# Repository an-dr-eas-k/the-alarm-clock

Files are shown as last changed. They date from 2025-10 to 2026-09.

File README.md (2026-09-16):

# Intro

# Getting started

1. Write Raspberry Pi OS to sd-card with the use of Raspberry Pi Imager.
   * lite distribution is enough
   * configure login and wifi

1. call the following script 
   * for main:
     ```
     nohup sh -c "curl https://raw.githubusercontent.com/an-dr-eas-k/the-alarm-clock/main/rpi/setup.sh | bash -s" &
     ```

   * for develop:
     ```
     nohup sh -c "curl https://raw.githubusercontent.com/an-dr-eas-k/the-alarm-clock/refs/heads/develop/rpi/setup.sh | bash -s" &
     ```

    * after: 
      ```
      reboot
      ```

    * repeat:
      ```
      nohup sh -c "curl https://raw.githubusercontent.com/an-dr-eas-k/the-alarm-clock/refs/heads/develop/rpi/setup.sh | bash -s -- fast" &
      ```

1. follow the log output with
   * for the application itself
     ```
     journalctl SYSLOG_IDENTIFIER=the-alarm-clock.service -f
     ```
   * for spotify events
     ```
     journalctl SYSLOG_IDENTIFIER=the-alarm-clock.spotify-event.service -f
     ```

# Dependencies
7 Segment Font is included from https://github.com/keshikan/DSEG/releases \
weather symbols are included from https://github.com/erikflowers/weather-icons

# Google Login & Calendar Integration

The web UI can require a Google login to edit settings, and it can show
calendar events (and play a reminder sound shortly before an accepted
event starts) for the Google accounts that logged in.

Since the device has no stable, publicly reachable hostname, login uses
Google's **OAuth 2.0 Device Authorization flow** (the same mechanism used by
smart TVs/streaming devices). No redirect URI is needed — Google's servers
never contact the device directly; the user just opens a short link on
their phone or computer and enters a short code shown by the alarm clock.

Setup:
1. In the [Google Cloud Console](https://console.cloud.google.com/), create
   an OAuth 2.0 Client ID of type **"TV and Limited Input devices"**.
2. Enable the **Google Calendar API** for the project.
3. Save the resulting client id/secret as
   `src/resources/google_oauth_secret.json`:
   ```json
   {
     "client_id": "....apps.googleusercontent.com",
     "client_secret": "...."
   }
   ```
   This file is git-ignored and never leaves the device.
4. Add the Google account email addresses that are allowed to log in to
   `allowed_google_emails` in `config.json` (or via the web UI's Config
   section once you have logged in once, e.g. by temporarily adding your own
   email directly to `config.json`).
5. Log in from the web UI ("Login with Google"): it shows a code and a link
   to `google.com/device` — open it on any device and enter the code.
6. Once logged in, the linked account's calendar is polled periodically;
   events starting within the next hour are shown on the display, and a
   configurable reminder sound plays a few seconds before any *accepted*
   event starts.

All related settings (reminder sound, lead time, poll interval, display
window) are editable in the web UI's Config section once logged in.

# Box

## Simple

# Connection Guide
## RPi GPIO

| |||||||||
|---|---|---|----|---|----|---|---|---|
| blue |  i2c (vcc) | 3V3 |  1 | |  2 | 5V  | | |
| green |  i2c (sda) | GPIO02 |  3 | |  4 | 5V  | | |
| yellow  |  i2c (scl) | GPIO03 |  5 | |  6 | GND  | | |
| purple  |  i2c (int) | GPIO04 |  7 | |  8 | GPIO14  | | |
| | | GND |  9 | | 10 | GPIO15  | | |
| | | GPIO17 | 11 | | 12 | GPIO18  | i2s (digiamp+)  | |
| | | GPIO27 | 13 | | 14 | GND  | | |
| | | GPIO22 | 15 | | 16 | GPIO23  | | |
| red | spi (vbat, 2)  | 3V3 | 17 | | 18 | GPIO24  | spi ( dc, 14) | gray  |
| white | spi ( sdi, 5)  | GPIO10 | 19 | | 20 | GND  | spi (  vss,  1) |  black  |
| | | GPIO09 | 21 | | 22 | GPIO25  | spi (reset, 15) | pink  |
| brown | spi (sclk, 4)  | GPIO11 | 23 | | 24 | GPIO08  | spi ( cs, 16) | blue  |
| | | GND | 25 | | 26 | GPIO07  | | |
| | | GPIO00 | 27 | | 28 | GPIO01  | invoke_button | |
| | rot_press | GPIO05 | 29 | | 30 | GND  | | |
| | rot_a | GPIO06 | 31 | | 32 | GPIO12  | mode_button | |
| | rot_b | GPIO13 | 33 | | 34 | GND  | | |
| | i2s (digiamp+) | GPIO19 | 35 | | 36 | GPIO16  | | |
| | | GPIO26 | 37 | | 38 | GPIO20  |  i2s (digiamp+) | |
| black | ground term | GND | 39 | | 40 | GPIO21  |  i2s (digiamp+) | |

## MCP 23017

| |||||||||
|---|---|----|---|---|---|---|---|---|
| | A3 | | VCC |  blue  | BH1759 | GND | | |
| | A2 | | ITB *1 | | | ITA *1  |  purple  | rpi gpio4 |
| | A1 | | B0 |  brown | rotary button | A0 |  white | mode button |
| | Reset | | B1 |  black | rotary 1 | A1 |  grey | invoke button |
| | NC | | B2 |  red | rotary 2 | A2 | | |
| | NC | | B3 | | | A3 | | |
| green | SDA | | B4 | | | A4 | | |
| orange  | SCL | | B5 | | | A5 | | |
| purple  | GND | | B6 | | | A6 | | |
| orange  | VCC | | B7 | | | A7 | | |

# State Diagram

|State|1|2|3|4| Comment|
|---|-----|-----|--|--| --|
|Default|Default,<br>Volume Timer|Default,<br> Volume Timer|AlarmView|Media On, Playing|
|Volume Timer | 
|AlarmView | AlarmView,<br>Previous Alarm | AlarmView,<br>Next Alarm | Default|AlarmEdit |There is a `new Alarm` Alarm|
|AlarmEdit | AlarmEdit,<br>Previous Property|AlarmEdit,<br>Next Property|Default|PropertyEdit|There is a `save` Property|
|PropertyEdit | PropertyEdit,<br>Value Down | PropertyEdit,<br>Value Up| Default | AlarmEdit|

# Devices
## Rotary Encoder
## Light Sensor BH1750
## Port Expander 16-Bit-I/O MCP23017 
## Sound card DigiAMP+

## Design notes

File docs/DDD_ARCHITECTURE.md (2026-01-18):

# Domain-Driven Design Architecture

## Layer Overview

This project follows **Domain-Driven Design (DDD)** principles with clear separation of concerns across four layers:

```
┌─────────────────────────────────────────────────────────┐
│                    INTERFACE LAYER                       │
│  (User interaction, Hardware I/O, API endpoints)        │
│                                                          │
│  • display/display_content.py  (ViewModel - MVVM)       │
│  • display/presenter.py         (View logic)             │
│  • display/format.py            (Display formatting)     │
│  • hardware_input_handler.py   (Hardware → Domain)      │
│  • web/template.html            (Web UI)                 │
└─────────────────────────────────────────────────────────┘
                          ↓ depends on
┌─────────────────────────────────────────────────────────┐
│                   APPLICATION LAYER                      │
│  (Use cases, orchestration, workflows)                  │
│                                                          │
│  • controls.py                  (Main orchestrator)      │
│  • api.py                       (REST API handlers)      │
│  • di_container.py              (Dependency injection)   │
└─────────────────────────────────────────────────────────┘
                          ↓ depends on
┌─────────────────────────────────────────────────────────┐
│                     DOMAIN LAYER                         │
│  (Pure business logic, no technical dependencies)       │
│                                                          │
│  Aggregates:                                             │
│  • AlarmClockContext            (Aggregate Root)         │
│  • EnvironmentContext           (Environment state)      │
│  • Config                       (Configuration)          │
│                                                          │
│  Entities:                                               │
│  • AlarmDefinition              (Alarm configuration)    │
│  • AlarmClockModeCoordinator    (UI mode management)     │
│                                                          │
│  Value Objects:                                          │
│  • RoomBrightness               (Display brightness)     │
│  • AudioStream, AudioEffect     (Audio configuration)    │
│  • VisualEffect                 (Alarm visual effects)   │
│                                                          │
│  Domain Events:                                          │
│  • AudioStreamChangedEvent                               │
│  • VolumeChangedEvent                                    │
│  • AlarmEvent                                            │
└─────────────────────────────────────────────────────────┘
                          ↓ depends on
┌─────────────────────────────────────────────────────────┐
│                 INFRASTRUCTURE LAYER                     │
│  (External systems, persistence, hardware)              │
│                                                          │
│  • audio.py                     (VLC playback)           │
│  • persistence.py               (JSON storage)           │
│  • brightness_sensor.py         (BH1750 sensor)          │
│  • event_bus.py                 (Event infrastructure)   │
│  • mcp23017/                    (Hardware buttons)       │
└─────────────────────────────────────────────────────────┘
```

## Key DDD Patterns Implemented

### 1. **Aggregates**

**AlarmClockContext** (Aggregate Root)
- Central entry point for domain operations
- Coordinates Config, EnvironmentContext, and ModeCoordinator
- Enforces invariants and business rules
- Location: `core/domain/model.py`

**EnvironmentContext** (Aggregate)
- Encapsulates environmental state (weather, network, location)
- Owned by AlarmClockContext
- Location: `core/domain/model.py`

### 2. **Value Objects**

**RoomBrightness**
- Immutable value representing ambient brightness
- Contains behavior: `is_highly_dimmed()`, `get_grayscale_value()`
- Used throughout the system for consistent brightness handling

**NextAlarmInfo**
- Immutable value representing next alarm timing
- Shields domain from infrastructure (APScheduler Job)
- Location: `core/interface/display/display_content.py`

### 3. **Entities**

**AlarmDefinition**
- Has identity (id field)
- Mutable lifecycle (can be edited, activated/deactivated)
- Rich domain behavior: `to_cron_trigger()`, `is_recurring()`

**AlarmClockModeCoordinator**
- Domain entity managing UI mode transitions
- Isolated from hardware through HardwareInputHandler

### 4. **Domain Events**

Events represent **business facts** that happened:
- `AlarmEvent` - An alarm was triggered
- `AudioStreamChangedEvent` - Audio source changed
- `VolumeChangedEvent` - Volume was adjusted
- `WifiStatusChangedEvent` - Network connectivity changed

Located in: `core/domain/events.py`

### 5. **Repositories** (Future Enhancement)

Currently using direct persistence, but planned:
```python
# core/repositories.py
class AlarmDefinitionRepository(ABC):
    @abstractmethod
    def get_by_id(self, id: int) -> AlarmDefinition: ...
    
    @abstractmethod
    def save(self, alarm: AlarmDefinition): ...
```

### 6. **Application Services**

**Controls** (Application Service)
- Orchestrates domain operations
- Coordinates between aggregates
- Manages scheduler and external systems
- Does NOT contain business logic (delegates to domain)

**AlarmEditingService** (Application Service)
- Manages alarm editing workflow
- Uses AlarmEditingSession aggregate
- Coordinates UI state with domain changes

### 7. **Anti-Corruption Layer**

**HardwareInputHandler** (Interface Layer)
- Translates hardware events (HwButtonEvent) to domain commands
- Prevents infrastructure leakage into domain
- Maps rotary encoder events to volume adjustments

**DisplayContent** (Interface Layer)
- ViewModel pattern (MVVM)
- Aggregates domain data for presentation
- Shields View from domain complexity

## Layering Rules (Dependency Inversion)

### ✅ Allowed Dependencies

```
Interface → Application → Domain → (nothing)
Infrastructure → Domain (via interfaces)
```

### ❌ Forbidden Dependencies

```
Domain → Infrastructure  ❌
Domain → Interface       ❌
Domain → Application     ❌
```

## Example: Adding a New Feature (DDD Way)

**Scenario:** Add "snooze alarm" feature

### 1. **Domain Layer** (Business Logic)
```python
# core/domain/model.py
class AlarmDefinition:
    def snooze(self, minutes: int = 10) -> datetime:
        """
        Business rule: Snooze moves alarm forward by configured minutes.
        Returns the new alarm time.
        """
        if not self.is_active:
            raise DomainException("Cannot snooze inactive alarm")
        
        snooze_time = GeoLocation().now() + timedelta(minutes=minutes)
        self.set_future_date(snooze_time.hour, snooze_time.minute)
        return snooze_time
```

### 2. **Application Layer** (Orchestration)
```python
# core/application/controls.py
def snooze_current_alarm(self):
    """
    Application service: Orchestrates snooze operation.
    """
    alarm_def = self._get_current_alarm()
    new_time = alarm_def.snooze(self.config.snooze_duration_mins)
    
    # Reschedule in infrastructure
    self.scheduler.add_job(...)
    
    # Emit domain event
    self.event_bus.emit(AlarmSnoozedEvent(new_time))
```

### 3. **Interface Layer** (User Interaction)
```python
# core/interface/hardware_input_handler.py
def _handle_snooze_button(self, event: HwButtonEvent):
    """
    Translate hardware button to domain command.
    """
    self.mode_coordinator.snooze_alarm()
```

### 4. **Infrastructure Layer** (External Systems)
```python
# core/infrastructure/audio.py
def stop_alarm_playback(self):
    """Stop VLC playback (infrastructure detail)."""
    self.player.stop()
```

## Benefits of This Architecture

### 1. **Testability**
- Domain logic testable without hardware
- Mock interfaces for infrastructure
- Unit test business rules in isolation

### 2. **Flexibility**
- Swap VLC for another audio player
- Replace JSON persistence with database
- Change display technology without touching domain

### 3. **Maintainability**
- Business logic concentrated in domain layer
- Clear responsibility boundaries
- Changes localized to appropriate layers

### 4. **Ubiquitous Language**
- Code speaks the business domain
- `AlarmDefinition.snooze()` not `schedule_timer()`
- `EnvironmentContext.is_daytime` not `check_sun_api()`

## Migration Path

### Current State (✅ Completed)
- [x] Domain layer separated from infrastructure
- [x] DisplayContent moved to interface layer
- [x] HardwareInputHandler as anti-corruption layer
- [x] Aggregates with clear boundaries

### Next Steps (Recommended)
- [ ] Extract PlaybackContent to interface layer
- [ ] Implement Repository pattern for persistence
- [ ] Move audio player creation to factory in infrastructure
- [ ] Add domain event sourcing for audit trail
- [ ] Create bounded contexts for complex domains

## File Organization

```
src/core/
├── domain/                    # PURE BUSINESS LOGIC
│   ├── model.py              # Aggregates, Entities, Value Objects
│   ├── mode_coordinator.py   # Mode management entity
│   ├── edit_mode.py          # Editing workflow
│   └── events.py             # Domain events
│
├── application/               # ORCHESTRATION
│   ├── controls.py           # Main application service
│   ├── api.py                # REST API handlers
│   └── di_container.py       # Dependency injection
│
├── interface/                 # USER/HARDWARE INTERACTION
│   ├── display/
│   │   ├── display_content.py    # ViewModel (THIS IS KEY!)
│   │   ├── presenter.py          # View logic
│   │   └── format.py             # Display formatting
│   ├── hardware_input_handler.py # Hardware → Domain
│   └── web/                      # Web interface
│
└── infrastructure/            # EXTERNAL SYSTEMS
    ├── audio.py              # VLC integration
    ├── persistence.py        # JSON storage
    ├── event_bus.py          # Event infrastructure
    └── mcp23017/             # Hardware drivers
```

## Key Takeaway

**The domain layer knows NOTHING about:**
- Display technology (OLED, TFT, etc.)
- Audio players (VLC, mpg123, etc.)
- Persistence (JSON, SQLite, etc.)
- Hardware (buttons, sensors, etc.)
- Web frameworks (Tornado, Flask, etc.)

**The domain layer knows ONLY:**
- Alarms can be snoozed
- Alarms have recurrence patterns
- Volume has min/max limits
- Weather affects display brightness

This is the essence of Domain-Driven Design!

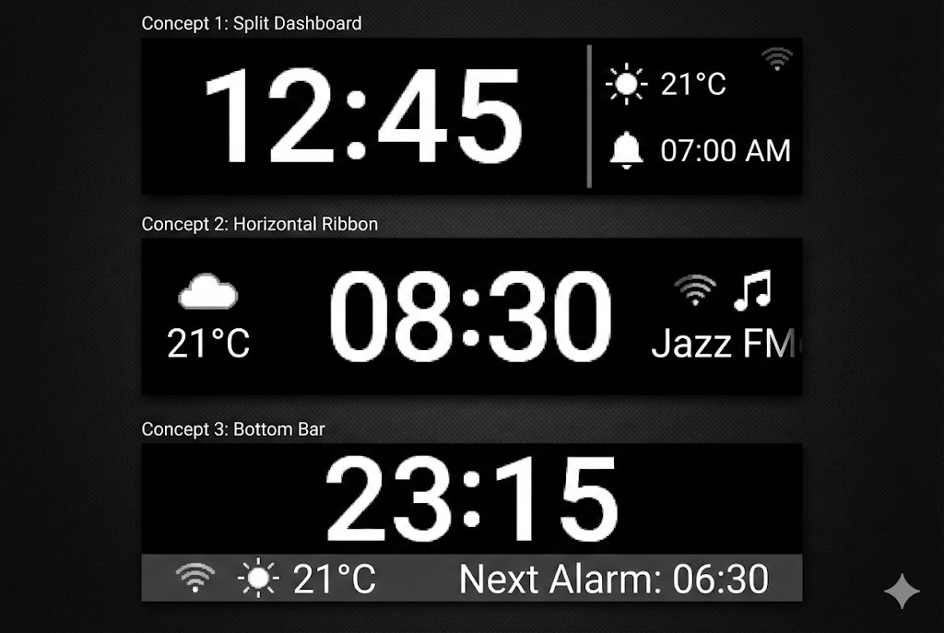
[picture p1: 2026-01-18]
docs/display_concepts.jpg

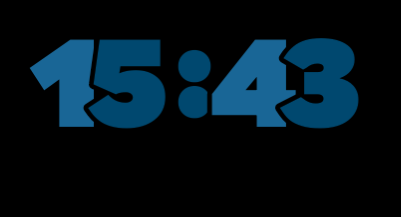
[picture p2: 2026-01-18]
docs/share_7980132162714593532.png

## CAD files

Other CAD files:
case/simple.dxf

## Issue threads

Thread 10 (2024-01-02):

action buttons in alarm.html

an-dr-eas-k, 2024-01-02:
update, reboot, and shutdown

Closed 2024-01-04.

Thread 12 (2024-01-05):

Dismiss alarm, repeat off button, why?

an-dr-eas-k, 2024-01-05:

an-dr-eas-k, 2024-01-30:
no idea, loose hardware connection

Closed 2024-01-30.

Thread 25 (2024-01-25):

display issues

an-dr-eas-k, 2024-01-25:
1. first digit in hour is malformed (done)
2. positive temperature, use ! instead of ' ' (done)
3. after bright display, flash with black
4. Transparent subtleness (fonts are more anti-aliased than needed. need to look into the way, the transparent layers are merged)

an-dr-eas-k, 2024-01-26:
1 and 2 are solved now

Closed 2024-03-19.

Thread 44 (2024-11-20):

Volume timer problem with offline alarm

an-dr-eas-k, 2024-11-20:
Volume Meter is showing when offline alarm chimes and is not dismissed automatically

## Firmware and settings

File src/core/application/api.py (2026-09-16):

import base64
import io
import logging
import os
import json
import subprocess
import traceback
import tornado
from concurrent.futures import ThreadPoolExecutor
import tornado.ioloop
import tornado.web
from PIL.Image import Image
from core.application.alarm_audio_service import AlarmAudioService
from core.application.calendar_service import CalendarService
from core.domain.events import (
    PlaybackChangedEvent,
    ConfigChangedEvent,
    ShutdownSystemRequest,
    SpotifyApiEvent,
    TerminateAppRequest,
    VolumeChangeRequest,
    WifiStatusChangedEvent,
)
from core.infrastructure.event_bus import EventBus
from core.interface.display.display import Display
from core.interface.display.format import ColorType
from core.interface.web.auth import (
    CurrentUserMixin,
    GoogleLoginPollHandler,
    GoogleLoginStartHandler,
    LogoutHandler,
)
from resources.resources import webroot_file, ssl_dir, icons_dir, fonts_dir

from core.domain.model import (
    AlarmDefinition,
    AudioEffect,
    AudioStream,
    Config,
    DisplayContentProvider,
    Mode,
    StreamAudioEffect,
    VisualEffect,
    Weekday,
)

logger = logging.getLogger("tac.core.application.api")


def try_update(object, property_name: str, value: str) -> bool:
    if hasattr(object, property_name):
        attr_value = getattr(object, property_name)
        attr_type = type(attr_value)
        if attr_type == bool:
            value = value.lower() in ["on", "yes", "true", "t", "1"]
        elif attr_type == list:
            value = json.loads(value) if value else []
        else:
            value = attr_type(value) if len(value) > 0 else None
        if value != attr_value:
            setattr(object, property_name, value)
        return True
    return False


def parse_path_arguments(path) -> tuple[str, int, str]:
    path_args = path[0].split("/")
    return (
        path_args[0],
        int(path_args[1]) if len(path_args) > 1 else None,
        path_args[2] if len(path_args) > 2 else None,
    )


class LibreSpotifyEventHandler(tornado.web.RequestHandler):

    def initialize(self, event_bus: EventBus, executor: ThreadPoolExecutor) -> None:
        self.event_bus = event_bus
        self.executor = executor

    def post(self):
        self.executor.submit(self.handle_spotify_event)
        self.finish()

    def handle_spotify_event(self):
        try:
            body = (
                "{}"
                if self.request.body is None or len(self.request.body) == 0
                else self.request.body
            )
            spotify_event_payload: dict[str, str] = tornado.escape.json_decode(body)

            spotify_event_dict = {
                key: value for key, value in spotify_event_payload.items()
            }

            spotify_event = SpotifyApiEvent(spotify_event_dict)
            logger.info("received librespotify event %s", spotify_event)
            self.event_bus.emit(spotify_event)
        except Exception:
            logger.warning("%s", traceback.format_exc())


class DisplayHandler(tornado.web.RequestHandler):

    def initialize(self, display: DisplayContentProvider) -> None:
        self.display = display

    def get(self):
        buffered = io.BytesIO()
        img = self.display.current_display_image
        assert isinstance(img, Image)
        img.save(buffered, format="png")
        img.seek(0)
        img_str = base64.b64encode(buffered.getvalue())
        my_html = '<img src="data:image/png;base64, {}">'.format(
            img_str.decode("utf-8")
        )
        self.write(my_html)


class ConfigHandler(CurrentUserMixin, tornado.web.RequestHandler):

    def initialize(self, config: Config, api: "Api") -> None:
        self.config = config
        self.api = api

    def get(self, *args, **kwargs):
        try:
            self.render(
                os.path.basename(webroot_file),
                config=self.config,
                api=self.api,
                calendar_events=self.api.calendar_service.get_upcoming_events(),
                current_user_picture=self.get_current_user_picture(),
            )
        except:
            logger.warning("%s", traceback.format_exc())


class ActionApiHandler(CurrentUserMixin, tornado.web.RequestHandler):

    def initialize(self, config: Config, event_bus: EventBus) -> None:
        self.config = config
        self.event_bus = event_bus

    @tornado.web.authenticated
    def post(self, *args):
        try:
            type, id, _1 = parse_path_arguments(args)
            logger.info("API action requested: %s %s", type, id)

            if type == "play":
                self.event_bus.emit(
                    PlaybackChangedEvent(
                        playback_mode=Mode.Music,
                        audio_stream=self.config.get_audio_stream_by_id(id),
                    )
                )
            elif type == "stop":
                self.event_bus.emit(PlaybackChangedEvent(Mode.Idle))
            elif type == "volume":
                if id == 1:
                    self.event_bus.emit(VolumeChangeRequest(relative=+1))
                else:
                    self.event_bus.emit(VolumeChangeRequest(relative=-1))
            elif type == "update":
                self.event_bus.emit(TerminateAppRequest())

                tornado.ioloop.IOLoop.current().stop()

            elif type == "reboot":
                self.event_bus.emit(ShutdownSystemRequest(reboot=True))
            elif type == "shutdown":
                self.event_bus.emit(ShutdownSystemRequest())
            else:
                logger.warning("Unknown action: %s", type)

        except:
            logger.warning("%s", traceback.format_exc())


class SystemApiHandler(CurrentUserMixin, tornado.web.RequestHandler):

    def initialize(self, event_bus: EventBus) -> None:
        self.event_bus = event_bus

    @tornado.web.authenticated
    def post(self, *args):
        try:
            type, _, _ = parse_path_arguments(args)
            logger.info("System API action requested: %s", type)

            if type == "wifi":
                status = self.get_argument("status", None)
                if status == "connected":
                    self.event_bus.emit(WifiStatusChangedEvent(is_online=True))
                elif status == "disconnected":
                    self.event_bus.emit(WifiStatusChangedEvent(is_online=False))
                else:
                    logger.warning("Unknown wifi status: %s", status)
            else:
                logger.warning("Unknown system action: %s", type)

        except:
            logger.warning("%s", traceback.format_exc())


class ConfigApiHandler(CurrentUserMixin, tornado.web.RequestHandler):

    def initialize(self, config: Config, event_bus: EventBus) -> None:
        self.config = config
        self.event_bus = event_bus

    def get(self):
        try:
            self.set_header("Content-Type", "application/json")
            self.write(self.config.serialize())
        except:
            logger.warning("%s", traceback.format_exc())

    @tornado.web.authenticated
    def delete(self, *args):
        try:
            self.parse_delete_payload(args)
            self.event_bus.emit(ConfigChangedEvent(self.config))
        except:
            logger.warning("%s", traceback.format_exc())

    def parse_delete_payload(self, args):
        type, id, _ = parse_path_arguments(args)
        if type == "alarm":
            self.config.remove_alarm_definition(id)
        elif type == "stream":
            self.config.remove_audio_stream(id)

    @tornado.web.authenticated
    def post(self, *args):
        try:
            self.parse_post_payload(args)
            self.event_bus.emit(ConfigChangedEvent(self.config))
        except:
            logger.warning("%s", traceback.format_exc())

    def parse_post_payload(self, args):
        type, id, property = parse_path_arguments(args)
        simpleValue = tornado.escape.to_unicode(self.request.body)
        if try_update(self.config, type, simpleValue):
            return
        alarmDef = self.config.get_alarm_definition_by_id(id)
        if (
            True
            and alarmDef is not None
            and property is not None
            and try_update(alarmDef, property, simpleValue)
        ):
            self.config.remove_alarm_definition(id)
            self.config.add_alarm_definition(alarmDef)
            return

        body = (
            "{}"
            if self.request.body is None or len(self.request.body) == 0
            else self.request.body
        )
        form_arguments = tornado.escape.json_decode(body)
        if type == "alarm":
            if id is not None:
                self.config.remove_alarm_definition(id)
            self.config.add_alarm_definition(
                self.parse_alarm_definition(form_arguments)
            )
        elif type == "stream":
            self.config.add_audio_stream(self.parse_audio_stream(form_arguments))
        elif type == "start_powernap":
            self.config.add_alarm_definition_for_powernap()

    def parse_audio_stream(self, form_arguments) -> AudioStream:
        stream_name = form_arguments["streamName"]
        stream_url = form_arguments["streamUrl"]
        return AudioStream(stream_name=stream_name, stream_url=stream_url)

    def parse_visual_effect(self, form_arguments) -> VisualEffect:
        use_visual_effect = (
            form_arguments.get("visualEffectActive") is not None
            and form_arguments["visualEffectActive"] == "on"
        )
        if use_visual_effect:
            return VisualEffect()
        return None

    def parse_audio_effect(self, form_arguments) -> AudioEffect:
        stream_id = int(form_arguments["streamId"])
        return StreamAudioEffect(
            audio_stream=self.config.get_audio_stream_by_id(stream_id),
            volume=float(form_arguments["volume"]),
        )

    def parse_alarm_definition(self, form_arguments) -> AlarmDefinition:
        ala = AlarmDefinition()
        ala.alarm_name = form_arguments["alarmName"]
        ala.hour, ala.min = map(int, form_arguments["time"].split(":"))
        ala.recurring = None
        ala.onetime = None
        if form_arguments.get("recurring") is not None:
            weekdays = form_arguments["recurring"]
            if not isinstance(weekdays, list):
                weekdays = [weekdays]
            ala.recurring = list(
                map(lambda weekday: Weekday[weekday.upper()].name, weekdays)
            )
        else:
            ala.set_future_date(ala.hour, ala.min)

        ala.audio_effect = self.parse_audio_effect(form_arguments)
        ala.visual_effect = self.parse_visual_effect(form_arguments)
        ala.is_active = (
            form_arguments.get("isActive") is not None
            and form_arguments["isActive"] == "on"
        )
        ala.fadein_in_secs = int(form_arguments.get("fadein_in_secs") or 0)
        ala.alarm_label = form_arguments.get("alarmLabel") or None
        return ala


class Api:

    app: tornado.web.Application

    def __init__(
        self,
        alarm_audio_service: AlarmAudioService,
        calendar_service: CalendarService,
        display: Display,
        event_bus: EventBus,
        executor: ThreadPoolExecutor,
        encrypted: bool,
    ):
        self.alarm_audio_service = alarm_audio_service
        self.calendar_service = calendar_service
        self.display = display
        self.event_bus = event_bus
        self.executor = executor
        self.encrypted = encrypted
        template_path = os.path.dirname(webroot_file)
        handlers = [
            (r"/display", DisplayHandler, {"display": self.display}),
            (
                r"/auth/google/start",
                GoogleLoginStartHandler,
                {
                    "calendar_service": self.calendar_service,
                    "executor": self.executor,
                },
            ),
            (
                r"/auth/google/poll",
                GoogleLoginPollHandler,
                {
                    "calendar_service": self.calendar_service,
                    "executor": self.executor,
                },
            ),
            (
                r"/auth/logout",
                LogoutHandler,
                {
                    "calendar_service": self.calendar_service,
                    "executor": self.executor,
                },
            ),
            (
                r"/api/config/?(.*)",
                ConfigApiHandler,
                {
                    "config": self.alarm_audio_service.alarm_clock_context.config,
                    "event_bus": self.event_bus,
                },
            ),
            (
                r"/api/action/?(.*)",
                ActionApiHandler,
                {
                    "config": self.alarm_audio_service.alarm_clock_context.config,
                    "event_bus": self.event_bus,
                },
            ),
            (
                r"/api/system/?(.*)",
                SystemApiHandler,
                {"event_bus": self.event_bus},
            ),
            (
                r"/api/librespotify",
                LibreSpotifyEventHandler,
                {"event_bus": self.event_bus, "executor": self.executor},
            ),
            (
                r"/media/(.*)",
                tornado.web.StaticFileHandler,
                {"path": icons_dir},
            ),
            (
                r"/fonts/(.*)",
                tornado.web.StaticFileHandler,
                {"path": fonts_dir},
            ),
            (
                r"/(.*)",
                ConfigHandler,
                {
                    "config": self.alarm_audio_service.alarm_clock_context.config,
                    "api": self,
                },
            ),
        ]

        self.app = tornado.web.Application(
            handlers,
            template_path=template_path,
            cookie_secret=self.alarm_audio_service.alarm_clock_context.config.cookie_secret,
            login_url="/",
        )

    def get_git_log(self) -> str:

        branch = "Branch: " + subprocess.check_output(
            ["git", "rev-parse", "--abbrev-ref", "HEAD"]
        ).decode("utf-8")

        log = subprocess.check_output(["git", "log", "-1"]).decode("utf-8")
        return f"{branch}\n{log}"

    def get_state_as_json(self) -> str:
        return json.dumps(
            obj=dict(
                room_brightness=self.alarm_audio_service.get_room_brightness(),
                display=dict(
                    foreground_color=self.display.formatter.foreground_color(
                        color_type=ColorType.IN16
                    ),
                    background_color=self.display.formatter.background_color(
                        color_type=ColorType.IN16
                    ),
                    refresh_duration_in_ms=self.alarm_audio_service.display_content.refresh_duration_in_ms,
                ),
                is_online=self.alarm_audio_service.alarm_clock_context.environment.is_online,
                is_daytime=self.alarm_audio_service.alarm_clock_context.environment.is_daytime,
                geo_location=self.alarm_audio_service.alarm_clock_context.environment.geo_location.location_info.__dict__,
                playback_content=dict(
                    audio_stream=self.alarm_audio_service.playback_content.audio_stream.__str__(),
                    volume=self.alarm_audio_service.playback_content.volume,
                    mode=self.alarm_audio_service.playback_content.playback_mode.name,
                ),
                uptime=subprocess.check_output(["uptime"]).strip().decode("utf-8"),
            ),
            indent=2,
        )

    def start(self):
        port = 443
        ssl_options = {
            "certfile": os.path.join(ssl_dir, "cert.crt"),
            "keyfile": os.path.join(ssl_dir, "cert.key"),
        }
        if not self.encrypted:
            ssl_options = None
            port = 8080

        self.app.listen(port, ssl_options=ssl_options)


if __name__ == "__main__":
    Api(8080).app.run()

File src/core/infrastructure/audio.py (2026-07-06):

import logging
import traceback
import vlc
import time
import subprocess
import threading
from concurrent.futures import ThreadPoolExecutor

from core.domain.events import (
    PlaybackChangedEvent,
    SpeakerErrorEvent,
)
from core.domain.model import (
    AudioStream,
    SpotifyStream,
)
from core.infrastructure.event_bus import EventBus
from resources.resources import init_logging

logger = logging.getLogger("tac.core.infrastructure.audio")


class MediaPlayer:

    error_callback: callable = None

    def play(self):
        pass

    def stop(self):
        pass

    def set_error_callback(self, callback: callable):
        self.error_callback = callback


class MediaListPlayer(MediaPlayer):
    def __init__(
        self,
        audio_stream: AudioStream,
        instance: vlc.Instance,
        executor: ThreadPoolExecutor,
    ):
        self.audio_stream = audio_stream
        self.instance = instance
        self.executor = executor
        self.list_player = None
        self.media = None
        self.media_list = None
        self._stop_monitoring = threading.Event()
        self._monitoring_future = None

    def _monitor_playback(self):
        logger.info("_monitor_playback thread started")
        while not self._stop_monitoring.is_set():
            try:
                if self.list_player is not None:
                    state = self.list_player.get_state()
                    if state == vlc.State.Error or state == vlc.State.Ended:
                        stream_name = (
                            self.audio_stream.stream_name
                            if self.audio_stream is not None
                            else "None"
                        )
                        logger.warning(
                            "Monitor detected %s state for stream: %s",
                            state,
                            stream_name,
                        )
                        if self.error_callback:
                            self.error_callback(self.audio_stream, state)
                        break
            except Exception:
                logger.error("Error in playback monitor: %s", traceback.format_exc())

            self._stop_monitoring.wait(1.0)

    def play(self):
        if self.list_player is not None:
            return

        if self.audio_stream is None:
            logger.warning("no audio stream provided")
            return

        stream_url = self.audio_stream.stream_url

        try:
            self.list_player = self.instance.media_list_player_new()
            self.list_player.set_playback_mode(vlc.PlaybackMode.loop)

            self.media = self.instance.media_new(stream_url)
            self.media_list = self.instance.media_list_new([])
            self.list_player.set_media_list(self.media_list)
            self.media_list.add_media(self.media)

            self._stop_monitoring.clear()
            self._monitoring_future = self.executor.submit(self._monitor_playback)

            logger.info("starting audio %s", stream_url)
            self.list_player.play()
        except Exception:
            logger.error("Error starting playback: %s", traceback.format_exc())
            self.stop()

    def stop(self):
        if self._monitoring_future:
            self._stop_monitoring.set()
            self._monitoring_future = None

        if self.list_player:
            try:
                self.list_player.stop()
            except Exception:
                pass

            if self.media_list:
                self.media_list.release()
                self.media_list = None
            if self.media:
                self.media.release()
                self.media = None

            self.list_player.release()
            self.list_player = None

        logger.info(f"stopped audio")


class Speaker:
    media_player: MediaPlayer = None
    fallback_player_proc: subprocess.Popen = None

    def __init__(
        self,
        event_bus: EventBus,
        vlc_instance: vlc.Instance,
        executor: ThreadPoolExecutor,
    ) -> None:
        self.threadLock = threading.Lock()
        self.event_bus = event_bus
        self.event_bus.on(PlaybackChangedEvent)(self._playback_changed)
        self.vlc_instance = vlc_instance
        self.executor = executor

    def _playback_changed(self, event: PlaybackChangedEvent):
        if isinstance(event.audio_stream, SpotifyStream):
            self.adjust_streaming(None)
            return

        self.adjust_streaming(event.audio_stream)

    def adjust_streaming(self, audio_stream: AudioStream):
        self.threadLock.acquire(True)

        if audio_stream is not None:
            self.start_streaming(audio_stream)
        else:
            self.stop_streaming()

        self.threadLock.release()

    def get_player(self, audio_stream: AudioStream) -> MediaPlayer:
        player: MediaPlayer = MediaListPlayer(
            audio_stream, self.vlc_instance, self.executor
        )
        player.set_error_callback(self.handle_player_error)
        return player

    def handle_player_error(
        self, audio_stream: AudioStream, player_state: vlc.State, *_
    ):
        self.event_bus.emit(SpeakerErrorEvent(audio_stream))

    def start_streaming(self, audio_stream: AudioStream):
        try:
            self.stop_streaming()
            self.media_player = self.get_player(audio_stream)
            self.media_player.play()
        except Exception as e:
            logger.error("error: %s", traceback.format_exc())
            self.handle_player_error(audio_stream)

    def stop_streaming(self):
        if self.media_player is not None:
            self.media_player.stop()
        self.media_player = None


def main():
    eb = EventBus()
    executor = ThreadPoolExecutor(max_workers=5)
    instance = vlc.Instance(
        ["--no-video", "--network-caching=3000", "--live-caching=3000", "--aout=alsa"]
    )
    s = Speaker(eb, instance, executor)
    stream = AudioStream(
        stream_name="test", stream_url="https://streams.br.de/bayern2sued_2.m3u"
    )
    s.adjust_streaming(stream)
    time.sleep(20)
    s.adjust_streaming(None)


def main_mlp():
    executor = ThreadPoolExecutor(max_workers=5)
    instance = vlc.Instance(["--aout=alsa"])
    stream = AudioStream(
        stream_name="test", stream_url="https://streams.br.de/bayern2sued_2.m3u"
    )
    mlp = MediaListPlayer(stream, instance, executor)
    mlp.play()
    time.sleep(10)
    mlp.stop()


if __name__ == "__main__":
    init_logging()
    main()

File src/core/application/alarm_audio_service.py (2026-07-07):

import datetime
import logging
import os
from core.application.basic_audio_service import BasicAudioService
from core.application.system_service import safe_action
from utils.geolocation import GeoLocation
from core.domain.events import (
    PlaybackChangedEvent,
    ConfigChangedEvent,
    StartupFinishedEvent,
    AlarmTriggeredEvent,
    PreAlarmTriggeredEvent,
    AlarmStoppedEvent,
    VolumeChangeRequest,
)
from core.domain.model import (
    AlarmClockContext,
    AlarmDefinition,
    NextAlarmInfo,
    PlaybackContent,
    Mode,
    SchedulerJobIds,
    StreamAudioEffect,
    Config,
)
from core.interface.display.display_content import DisplayContent
from core.infrastructure.brightness_sensor import IBrightnessSensor
from core.infrastructure.event_bus import EventBus
from core.infrastructure.scheduler import SchedulerService, SchedulerStores
from resources.resources import active_alarm_definition_file
from utils.extensions import get_job_arg
from utils.os_interactions import OSInteraction

logger = logging.getLogger("tac.core.application.alarm_audio_service")


class AlarmAudioService(BasicAudioService):
    def __init__(
        self,
        alarm_clock_context: AlarmClockContext,
        display_content: DisplayContent,
        playback_content: PlaybackContent,
        brightness_sensor: IBrightnessSensor,
        event_bus: EventBus,
        scheduler_service: SchedulerService,
        os_interaction: OSInteraction,
    ) -> None:
        super().__init__(
            alarm_clock_context,
            display_content,
            playback_content,
            brightness_sensor,
            event_bus,
            scheduler_service,
            os_interaction,
        )
        self.event_bus.on(AlarmTriggeredEvent)(self._alarm_triggered)
        self.event_bus.on(AlarmStoppedEvent)(self._alarm_stopped_event)
        self.event_bus.on(StartupFinishedEvent)(self._handle_startup_finished)
        self._volume_increase_start_time = None
        self._volume_increase_start_volume = None

    def consider_failed_alarm(self):
        if os.path.exists(active_alarm_definition_file):
            ad: AlarmDefinition = AlarmDefinition.deserialize(
                active_alarm_definition_file
            )
            ad.id = -1
            logger.info("failed audioeffect found %s", ad.alarm_name)
            self._ring_alarm(ad)

    def _handle_startup_finished(self, _: StartupFinishedEvent):
        self.consider_failed_alarm()

    def _config_changed(self, event: ConfigChangedEvent):
        config: Config = event.config
        self.scheduler_service.remove_all_jobs(jobstore=SchedulerStores.alarm.value)
        alDef: AlarmDefinition
        for alDef in config.alarm_definitions:
            if not alDef.is_active:
                continue
            logger.info("adding job for '%s'", alDef.alarm_name)
            self.scheduler_service.add_cron_job(
                func=self._ring_alarm,
                args=(alDef,),
                job_id=f"{alDef.id}",
                jobstore=SchedulerStores.alarm.value,
                **alDef.get_cron_args(),
            )
        self.scheduler_service.cleanup_alarms(config)
        self.update_next_alarm()

    def update_next_alarm(self):
        next_alarm_info: NextAlarmInfo = self.scheduler_service.get_next_alarm_info()
        if next_alarm_info.next_run_time is not None:
            self.scheduler_service.add_or_replace_date_job(
                func=self._trigger_pre_alarm,
                args=[next_alarm_info.alarm_definition],
                run_date=next_alarm_info.next_run_time
                - datetime.timedelta(
                    minutes=self.alarm_clock_context.config.pre_alarm_trigger_in_mins
                ),
                job_id=SchedulerJobIds.pre_alarm.value,
                jobstore=SchedulerStores.default.value,
            )
        self.display_content.update_next_alarm(next_alarm_info)
        self._update_alarm_sort_orders()
        logger.info(
            "next alarm info updated: %s",
            next_alarm_info if next_alarm_info.next_run_time else "none",
        )

    def _update_alarm_sort_orders(self):
        next_run_times = {}
        for job in self.scheduler_service.get_jobs(
            jobstore=SchedulerStores.alarm.value
        ):
            job_alarm_def: AlarmDefinition = get_job_arg(job, AlarmDefinition)
            if job_alarm_def is None or job.next_run_time is None:
                continue
            next_run_times[job_alarm_def.id] = job.next_run_time.timestamp()
        self.alarm_clock_context.config.alarm_definitions.sort(
            key=lambda a: (not a.is_active, next_run_times.get(a.id, float("inf")))
        )

    def _alarm_triggered(self, event: AlarmTriggeredEvent = None):
        self._preprocess_ring_alarm(event.alarm_definition)
        audio_effect = self._get_appropriate_alarm_effect()
        initial_volume = (
            self.alarm_clock_context.config.start_volume
            if getattr(event.alarm_definition, "fadein_in_secs", 0) > 0
            else audio_effect.volume
        )
        self.event_bus.emit(
            PlaybackChangedEvent(
                Mode.Alarm,
                audio_effect.audio_stream,
                absolute_volume=initial_volume,
            )
        )

        if event.alarm_definition.is_onetime() and event.alarm_definition.id >= 0:
            self.alarm_clock_context.config.remove_alarm_definition(
                event.alarm_definition.id
            )
            self.event_bus.emit(ConfigChangedEvent(self.alarm_clock_context.config))
        else:
            self.update_next_alarm()

    def _get_appropriate_alarm_effect(self) -> StreamAudioEffect:
        active_alarm_effect = (
            self.alarm_clock_context.active_alarm_definition.audio_effect
        )
        audio_effect = StreamAudioEffect(volume=active_alarm_effect.volume)
        if (
            False
            or not self.os_interaction.is_internet_available()
            or self.playback_content.playback_mode
            in [
                Mode.Music,
                Mode.Spotify,
            ]
        ):
            logger.info("adjusting alarm to use offline stream")
            audio_effect.audio_stream = (
                self.alarm_clock_context.config.get_offline_stream()
            )
        else:
            audio_effect.audio_stream = active_alarm_effect.audio_stream

        return audio_effect

    def _trigger_pre_alarm(self, alarm_definition: AlarmDefinition):
        def do():
            self.event_bus.emit(PreAlarmTriggeredEvent(alarm_definition))

        safe_action(
            do, "trigger pre-alarm '%s'" % alarm_definition.alarm_name, logger=logger
        )

    def _ring_alarm(self, alarm_definition: AlarmDefinition):
        def do():

            self.event_bus.emit(AlarmTriggeredEvent(alarm_definition))

        safe_action(do, "ring alarm '%s'" % alarm_definition.alarm_name, logger=logger)
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

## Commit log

2023-10-17 prepare environment switch to gpiozero
2023-11-07 power amplifyer
2023-11-14 refactor gpio for spi
2023-11-14 fix pin
2023-11-16 print exception
2023-11-16 print mode
2023-12-27 merge Develop (#8)
    * add displayhandler with image
    * use fonts
    * update alignment, draft nowifi
    * adjust gitignore
    * add livestream player
    * clean stuff, add domain classes
    * prepare environment
    switch to gpiozero
    * add observer pattern
    * continue observer pattern
    * update onboot
    * adjust notify
    * remove dependency
    * update controls
    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
    [api.py, audio.py, gpi.py]
2024-01-11 merge Develop (#18)
    * update clock with event
    * clean go()
    * add keyboard controls and fix observers
    * fix keylistener
    * add/move api
    * clean
    * update alarm config
    * continue the configuration
    refactor pynput
    * power amplifyer
    * fix
    * reduce dependency and
    add gpo class
    * use json to transmit to backend
    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
    [api.py, audio.py, gpi.py]
2024-01-13 Develop (#19)
    * seria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
2024-01-31 Develop (#26)
    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
    [api.py, audio.py]
2024-03-04 Develop (#27)
    * exception handling
    * print exception
    * fallback to hardware controls
    * try except
    * simplify
    * text only
    * time working now
    * reduce contrast
    * new size
    * adjust wifi symbol
    * ignore mask
    * manual shit
    * print mode
    * image handling
    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
    [api.py, audio.py]
2024-04-16 Develop (#36)
    * adjust vlc
    * some adjustments
    * adjust gpios
    * add sunevent, add logging
    * fixes
    * introduce geolocation singleton
    * move observer
    * add light sensor
    * adjust unit
    * normalize
    * add debugging msgs
    * hm
    * update
    * intro brightness function
    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
    [api.py, audio.py, gpi.py]
2024-04-26 Develop (#37)
    * add offline fallback alarm
    * impl alarm duration
    * add fallback player when exception occurs in media_player
    * add fast powernap
    * make visual effects configurable in alarms
    * new default init of config
    * remove powernap from config
    * add system beep
    * improve alarm audio
    * introduce offlinealarmeffect
    * unify guaranteed property
    * working solution
    * replace audio_effect by state
    * try volume settings
    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
    [rpi-boot-config.txt]
2024-09-24 Adjust display, fix stop alarm, use pigpio (#41)
    * add starter for spotify event
    * add equalizer and spotifyconfig
    * adjust dump
    * dont output logs directly, use syshandler
    * fix?
    * Update logging.conf
    * fix state on web
    * add info out
    * fix syntax
    * move concern
    * update scripts
    * update scripts
    * not sure
    * add dummy spotify player
    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
    [api.py, audio.py]
2024-10-22 update display refresh (#43)
    * connect spotifyapi
    * connect spotifyapi 2
    * adjust rpi setup
    * move display_content to playbackcontent title
    * alway seem successful
    * use finish
    * exit 0
    * hm?
    * stabilize
    * enable debug
    * add logging
    * disable debug
    * toggle to streamaudio
    * add track_id
    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
    [api.py]
2024-12-09 upgrade framework to enable modes
2024-12-17 fix buttons
2024-12-17 hide volume meter when switching to Idle mode
2024-12-18 fix volume button
2025-01-27 get functional with editing on device
2025-09-15 move button handling
2025-09-16 refactor devices
2025-09-17 switch to rpi-lgpio, disable pigpiod
2025-09-18 fix pin origins
2025-09-18 ignore pin being false
2025-09-21 init thread late
2025-09-21 adjust interrupt
2025-09-21 be a deamon thread
2025-09-21 interrupt on any pin
2025-09-21 fix pin names
2025-09-21 reduce interrupt pins
2025-10-07 update case
    [simple.dxf]
2025-10-12 move sound-device to di-container
2025-10-12 finish di refactoring
2025-11-01 wire up items
2025-11-10 switch to falling
2025-11-10 filter for falling
2025-11-10 dont filter
2025-11-25 fix and adjust player
    [audio.py]
2025-11-29 ignore up button event
2025-11-29 daemon mode for thread
2025-12-02 list threads
2025-12-03 measure brightness sensor
2025-12-04 add formatter to di
2025-12-05 release all vlc instances, name all threads
2025-12-05 threaded librespotify event handler
2025-12-05 import threading
2025-12-09 add thread profiler
2025-12-09 adjust thread profiler timing
2025-12-14 try to fix pynput problem
    [computer_infrastructure.py]
2025-12-15 print full memory usage
2025-12-15 run in thread
2025-12-16 refactor: remove wifi stability checks from alarm handling
    [system_service.py]
2025-12-16 refactor: remove unused thread usage logging from system service
2025-12-17 improve audio memory leak
    [audio.py]
2025-12-17 ignore thread report
2025-12-21 add thread name
2025-12-21 increase spi speed
2025-12-21 dont print logger name
2025-12-22 trace stach on qt errors
2026-01-02 fix button direction
2026-01-02 account for multi threading
2026-01-02 move to di
2026-01-05 fix my external keyboard
    [computer_infrastructure.py]
2026-01-05 clear device on shutdown
2026-01-05 add threadpoolexecutor
2026-01-06 dont clear interrupts
2026-01-06 add current pin value also
2026-01-19 install aic8800 driver
2026-01-21 handle track change
2026-01-21 use dkms to install wifi driver
2026-01-29 disable buttons
2026-01-29 enable invoke button
2026-01-30 enable button
2026-05-13 forward button direction
2026-05-18 Refactor _rotary_encoder_callback logic
    Remove early return in rotary encoder callback.
2026-07-07 Add StreamChangeRequest event and handle long press events for stream switching
2026-09-16 Add Google Calendar integration (OAuth device flow, calendar service, display)
